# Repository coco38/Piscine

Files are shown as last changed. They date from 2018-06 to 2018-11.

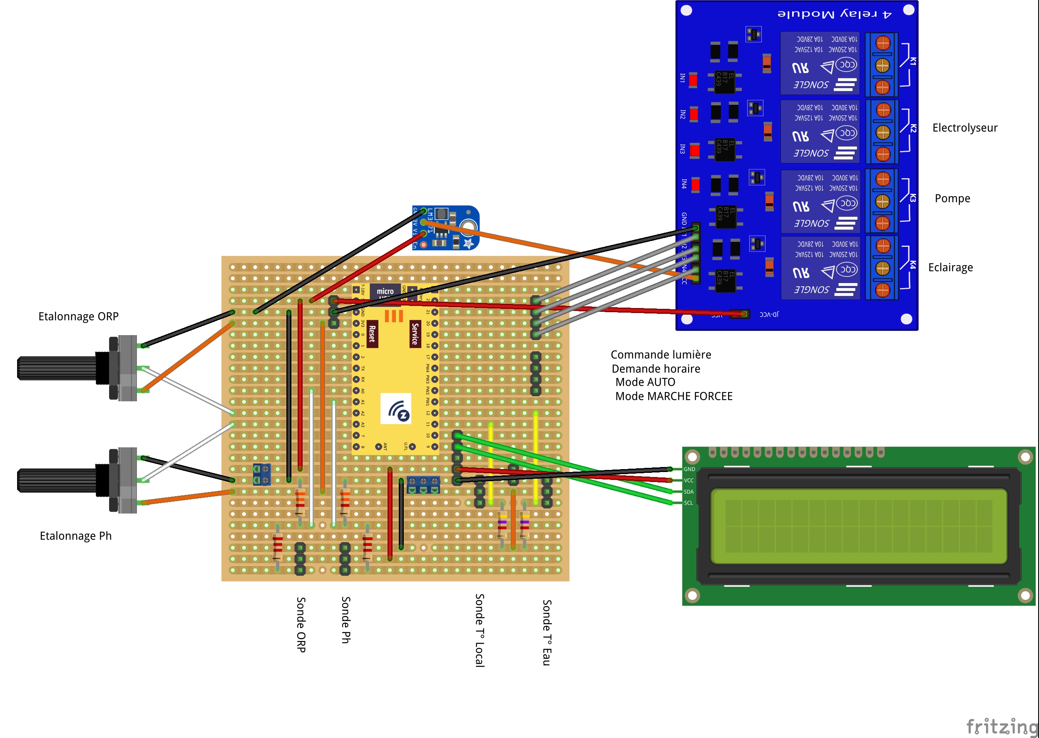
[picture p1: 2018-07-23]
Carte/Carte Design.jpg

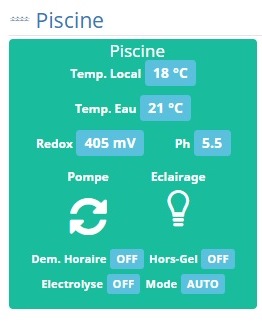
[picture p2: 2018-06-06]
Photos/Jeedom.jpg

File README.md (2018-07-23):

# Piscine

Pour ceux que ça intéresse, j'ai fait un automatisme largement inspiré du blog :
http://clement.storck.me/blog/2014/08/controle-et-supervision-de-la-piscine/

Pour les fonctions/informations, il intègre:
- remontée de la température du local
- remontée de la température de l'eau
- remontée du Ph
- remontée du Redox
- pilotage de l'éclairage à distance
- pilotage de la pompe à distance
- automatisme de la pompe
- régulation du chlore et mise en sécurité si la température de l'eau est inférieure à 15°C
- fonction Hors-Gel

Pour la gestion horaire, j'ai gardé la minuterie en façade de mon coffret d'origine.

Les 2 potentiomètres permettent de recaler les valeurs mesurées (ORP et Ph) pour corriger la dérive des sondes.

La principale différence par rapport au projet du blog citée précédemment, est le passage sur un Z-Uno. J'ai déjà un réseau Zwave et la gestion des commandes et des remontées d'informations à Jeedom est nettement plus facile.

Jérôme

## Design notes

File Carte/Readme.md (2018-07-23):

# Matériel:
- 1 carte Z-Uno
- 1 afficheur LCD 4x20 I2C
- 1 carte 4 relais 5V - 220V 10A
- 2 cartes Phidgets 1130
- 2 sondes de températures 1-Wire étanches (inox)
- 1 sonde ORP/Redox, plage du signal -2V/+2V
- 1 sonde de Ph, plage du signal 0V/1V
- 2 résistances 2,2kΩ
- 2 résistances 3.3kΩ
- 2 résistances 4.7kΩ
- 2 potentiomètres 10kΩ
- des fiches "Dupont" femelles, pas 1.54mm, à souder (pour enficher le Z-Uno)
- des fiches "Dupont" males, pas 1.54mm, à souder (pour brancher les sondes ORP, Ph et Températures)
- du fils et des connecteurs "Dupont" à sertir

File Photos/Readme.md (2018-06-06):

# Description des photos:
- Jeedom.jpg : vue du widget sous Jeedom
- Jeedom - Zuno commandes page 1.jpg : liste des commandes à créer (page 1)
- Jeedom - Zuno commandes page 2.jpg : liste des commandes à créer (page 2)
- Jeedom - Zuno valeurs.jpg : liste des valeurs remontées par le Zuno, suite à l'inclusion

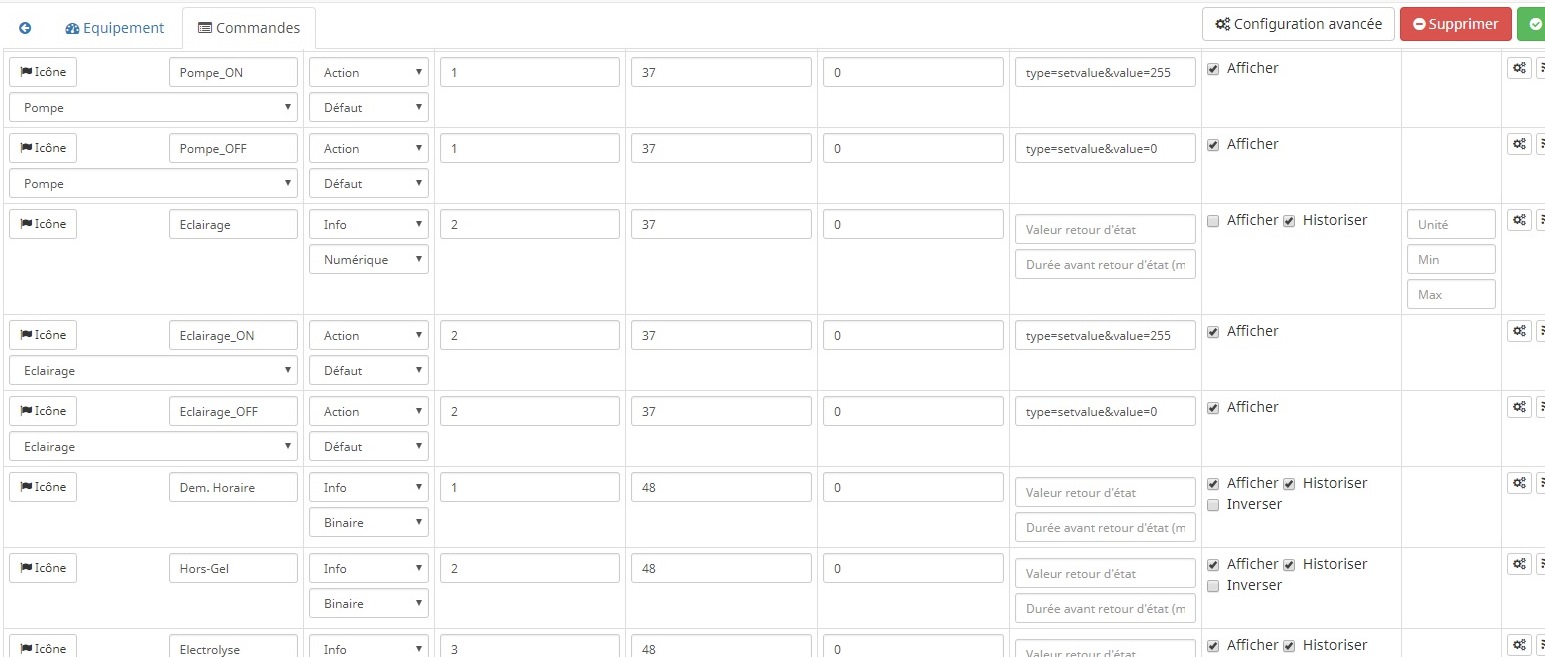
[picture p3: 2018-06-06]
Photos/Jeedom - Zuno commandes page 2.jpg

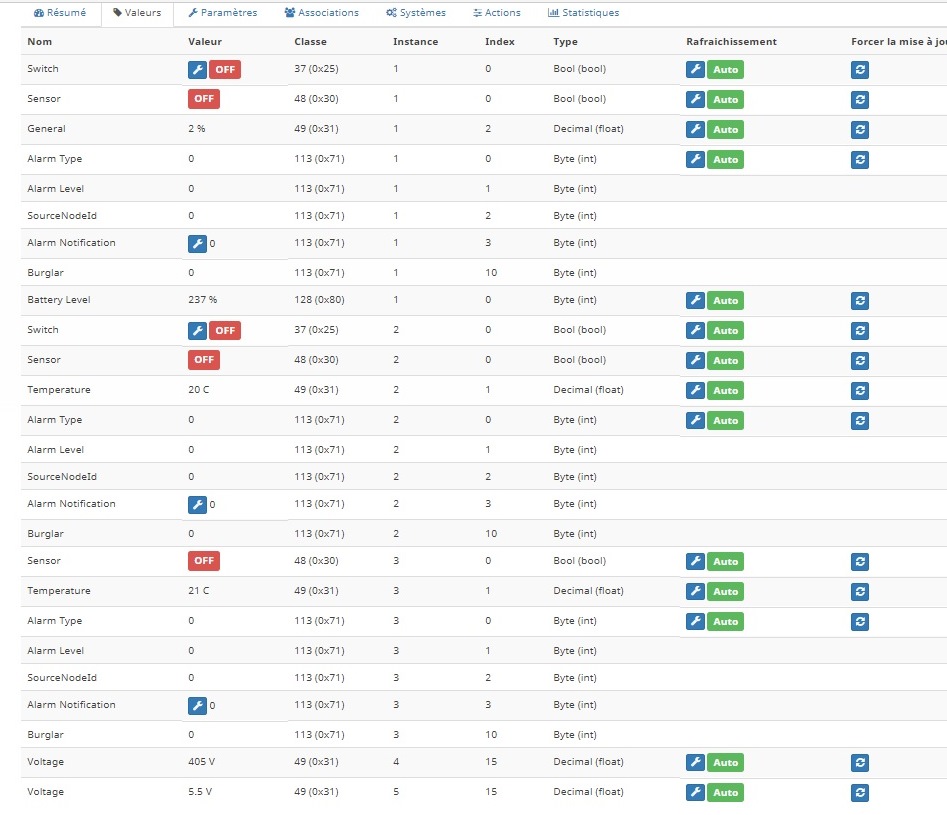
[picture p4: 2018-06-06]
Photos/Jeedom - Zuno valeurs.jpg

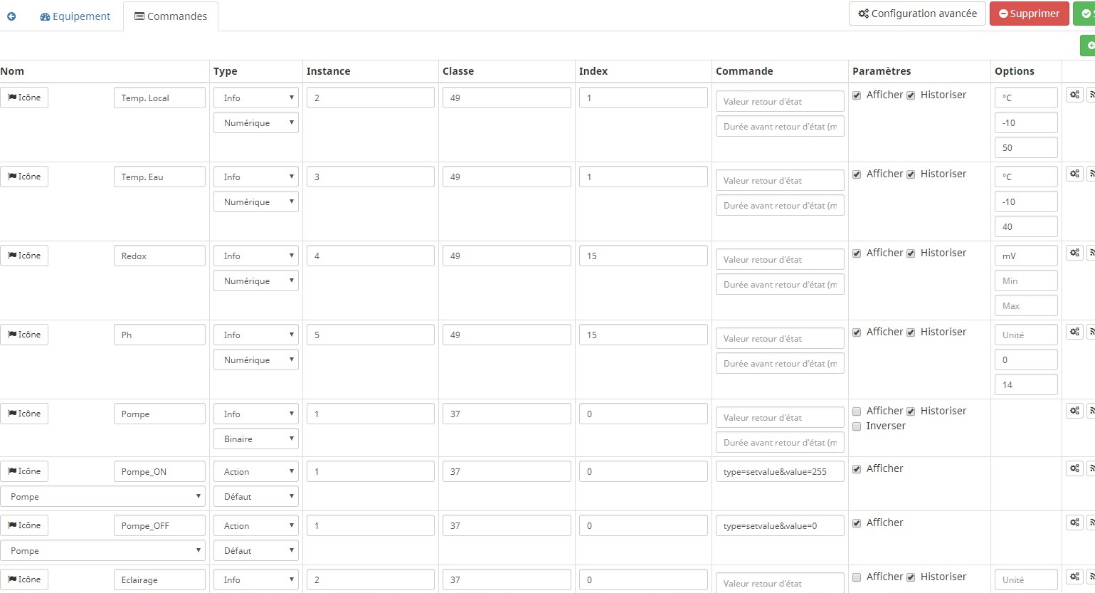
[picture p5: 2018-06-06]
Photos/Jeedom - Zuno commandes page 1.jpg

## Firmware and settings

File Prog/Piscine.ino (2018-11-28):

#include <ZUNO_OneWire.h>
#include <ZUNO_LCD_I2C.h>
#include <ZUNO_DS18B20.h>

/*******************************************
 * AFFECTATION DES PINS
 ******************************************/
//TEST
#define PIN_LED 13
#define PIN_BUTTON 18

//Entrée Ana
#define PIN_ORP         A0    // Pin de la sonde ORP
#define PIN_PH          A1    // Pin de la sonde PH
#define PIN_ORP_ETAL    A2    // Pin pour l'étalonnage de la sonde ORP
#define PIN_PH_ETAL     A3    // Pin pour l'étalonnage de la sonde PH

//Température
#define PIN_TEMP_LOCAL  11 // Pin du capteur DS18B20 : Température du local 
#define PIN_TEMP_EAU    12 // Pin du capteur DS18B20 : Température de l'eau

//Entrée TOR
#define PIN_MODE_MANU   14    // Pin du mode Manu
#define PIN_MODE_AUTO   15    // Pin du mode Auto
#define PIN_HORAIRE     16    // Pin du selecteur horaire
#define PIN_LUMIERE     17    // Pin du bouton lumiere

//Sortie relais
#define PIN_ECL_PISCINE   19  // Pin de l'éclairage de la piscine
#define PIN_POMP_PISCINE  20  // Pin de la pompe de la piscine
#define PIN_ELECTROLYSE   21  // Pin de l'electrolyseur

/*******************************************
 * CONSTANTES
 ******************************************/
//tension de reference (Vcc) du Zuno
#define VOLT_REFERENCE  3.05  // Tension de référence
 
//température
#define TEMP_GEL_MIN  -0.5  // Température de démarrage du mode antigel
#define TEMP_GEL_MAX   1.0  // Température d'arrêt du mode antigel
 
//ORP/Redox
#define ORP_MIN     660   // Tension (mV) de démarrage de la production de chlore
#define ORP_MAX     720   // Tension (mV) d'arrêt de la production de chlore

#define TempoMesure 300000  //attente entre chaque mesure
/******************************************
 * VARIABLES GLOBALES
 ******************************************/
//TEST
byte LedState;

//temporisation
unsigned long PrecMillis = 0;

//ecran lcd
LiquidCrystal_I2C lcd(0x3F, 20, 4);

//mode de fonctionnement
byte modePompe = 0; // 0:arret / 1:marche forcée / 2:auto
byte modePompePrec = 0;

//mesure de temperature
//Local
OneWire owTempLoc(PIN_TEMP_LOCAL);
DS18B20Sensor CapteurTempLoc(&owTempLoc);
int TemperatureLoc=0;
//Eau
OneWire owTempEau(PIN_TEMP_EAU);

DS18B20Sensor CapteurTempEau(&owTempEau);
int TemperatureEau=0;

//mesures
int valORP=0;
float valPH=0.0;

//sorties relais
//pompe
bool fctGel = false;
bool pinHoraire = false;
bool pinHorairePrec = false;
bool etatPompe = false;

//lumiere
bool pinLumiere = false;
bool pinLumierePrec = false;
bool etatLumiere = false;

//Chlore
bool etatChloreProd = false;

/******************************************
 * CANAUX ZWAVE
 * 1 : cmde de la pompe
 * 2 : cmde de la lumiere
 * 3 : mode AUTO (2) / MANU (1) / ARRET (0)
 * 4 : etat de la demande horaire
 * 5 : etat de la demande hors gel
 * 6 : température du local
 * 7 : température de l'eau
 * 8 : niveau ORP/Redox
 * 9 : niveau PH
 * 10 : etat production de Chlore
 ******************************************/

ZUNO_SETUP_CHANNELS(
  //Etat & commande de la pompe
  ZUNO_SWITCH_BINARY(getPompe, setPompe),
  //Etat & commande de la lumiere  
  ZUNO_SWITCH_BINARY(getLumiere, setLumiere),
  //Mode selectionne
  ZUNO_SENSOR_MULTILEVEL_GENERAL_PURPOSE(getMode),
  //Etat & commande de la pompe
  ZUNO_SENSOR_BINARY(ZUNO_SENSOR_BINARY_TYPE_GENERAL_PURPOSE, getHoraire),
  //Etat du mode hors-gel
  ZUNO_SENSOR_BINARY(ZUNO_SENSOR_BINARY_TYPE_GENERAL_PURPOSE, getGel),
  //Temperature du local
  ZUNO_SENSOR_MULTILEVEL(ZUNO_SENSOR_MULTILEVEL_TYPE_TEMPERATURE,SENSOR_MULTILEVEL_SCALE_CELSIUS, SENSOR_MULTILEVEL_SIZE_TWO_BYTES, SENSOR_MULTILEVEL_PRECISION_ONE_DECIMAL, getTempLocal),
  //Temperature de l'eau
  ZUNO_SENSOR_MULTILEVEL(ZUNO_SENSOR_MULTILEVEL_TYPE_TEMPERATURE,SENSOR_MULTILEVEL_SCALE_CELSIUS, SENSOR_MULTILEVEL_SIZE_TWO_BYTES, SENSOR_MULTILEVEL_PRECISION_ONE_DECIMAL, getTempEau),
  //ORP/Redox
  ZUNO_SENSOR_MULTILEVEL(ZUNO_SENSOR_MULTILEVEL_TYPE_VOLTAGE,SENSOR_MULTILEVEL_SCALE_VOLT, SENSOR_MULTILEVEL_SIZE_TWO_BYTES, SENSOR_MULTILEVEL_PRECISION_ZERO_DECIMALS, getORP),
  //Ph
  ZUNO_SENSOR_MULTILEVEL(ZUNO_SENSOR_MULTILEVEL_TYPE_VOLTAGE,SENSOR_MULTILEVEL_SCALE_VOLT, SENSOR_MULTILEVEL_SIZE_TWO_BYTES, SENSOR_MULTILEVEL_PRECISION_ONE_DECIMAL, getPH),
  //Etat de la production de chlore
  ZUNO_SENSOR_BINARY_GENERAL_PURPOSE(getChloreProd));

/******************************************
 * INITIALISATION
 ******************************************/
void setup() {
  //initialisation port serie
  Serial.begin(9600);
  Serial.println("Start...");

  Serial.println("Initialisation des sorties relais");
  pinMode(PIN_ECL_PISCINE, OUTPUT);
  pinMode(PIN_POMP_PISCINE, OUTPUT);
  pinMode(PIN_ELECTROLYSE, OUTPUT);

  Serial.println("Initialisation des entrees");
  pinMode(PIN_MODE_MANU, INPUT_PULLUP);
  pinMode(PIN_MODE_AUTO, INPUT_PULLUP);
  pinMode(PIN_HORAIRE, INPUT_PULLUP);
  pinMode(PIN_LUMIERE, INPUT_PULLUP);
        
  //initialisation écran lcd
  Serial.println("Initialisation de l'ecran LCD");
  delay(300);
  lcd.begin();
  lcd.backlight();
  lcd.setCursor(0,0);
  lcd.print("T");lcd.print((char)223);lcd.print(" Local:");
  lcd.setCursor(13,0);
  lcd.print("Eau:");
  lcd.setCursor(0,1);
  lcd.print("Redox:       ");
  lcd.setCursor(13,1);
  lcd.print("Ph:    ");
  lcd.setCursor(0,2);
  lcd.print("Mode:ARRET");
  lcd.setCursor(13,2);
  lcd.print("Lum:OFF");
  lcd.setCursor(0,3);
  lcd.print("Pompe:OFF Chlore:OFF"); 
  delay(100);
  
  pinMode(PIN_LED, OUTPUT);
  pinMode(PIN_BUTTON, INPUT_PULLUP);

  digitalWrite(PIN_LED, LOW);
  LedState=0;

  //initialisation des relais
  Serial.println("Initialisation des sorties relais");
  digitalWrite(PIN_ECL_PISCINE, HIGH);
  digitalWrite(PIN_POMP_PISCINE, HIGH);
  digitalWrite(PIN_ELECTROLYSE, HIGH);  

  PrecMillis = millis();
}

void loop() {

  lectureEntrees();
  
  if ((digitalRead(PIN_BUTTON)==0) || ((millis() - PrecMillis) >= TempoMesure)) {

    PrecMillis = millis();
    
    Serial.println("Button pressed");
    if(LedState==0){
      digitalWrite(PIN_LED, HIGH);
      LedState = 1;
      Serial.println("Led On");
    }
    else{
      digitalWrite(PIN_LED, LOW);
      LedState = 0;
      Serial.println("Led Off");    
    }

    //mesure de la température du local
    lectureTempLocal();    

    //si la pompe fonctionne, on fait les mesures de l'eau (ORP, PH, Temperature)
    if(etatPompe){

      lectureTempEau();
      lectureORP();
      lecturePH();
    }

    zunoSendReport(1);
    zunoSendReport(2);
    zunoSendReport(3);
    zunoSendReport(4);
    zunoSendReport(5);
    zunoSendReport(10);
  }

  //Mise à jour du fonctionnement de la pompe
  FctPompe();
  
  //pilotage du relais de la pompe et mise à jour de l'affichage LCD
  //Edit 29-Sep-2018
  if(etatPompe){
    digitalWrite(PIN_POMP_PISCINE,LOW);
    lcd.setCursor (6, 3);
    lcd.print("ON ");    
  }
  else{
    digitalWrite(PIN_POMP_PISCINE,HIGH);
    lcd.setCursor (6, 3);
    lcd.print("OFF");  
  }

  FctLumiere();
  
  //pilotage du relais de la lumiere et mise à jour de l'affichage LCD
  //Edit 29-Sep-2018 
  if(etatLumiere){
    digitalWrite(PIN_ECL_PISCINE, LOW);
    lcd.setCursor(17,2);
    lcd.print("ON ");
  }
  else {
    digitalWrite(PIN_ECL_PISCINE, HIGH);
    lcd.setCursor(17,2);
    lcd.print("OFF");    
  }

  FctProdChlore();
  
  //pilotage du relais de la production de chlore et mise à jour de l'affichage LCD
  //Edit 29-Sep-2018
  if(etatChloreProd){
    digitalWrite(PIN_ELECTROLYSE, LOW);
    lcd.setCursor (17, 3);
    lcd.print("ON ");
  }
  else {
    digitalWrite(PIN_ELECTROLYSE, HIGH);
    lcd.setCursor (17, 3);
    lcd.print("OFF");  
  }
  delay(120);
}

/****************************************************************************
 * FONCTION : récupère la température de l'eau du capteur DS18B20
 *  sans objet
 ****************************************************************************/
void lectureTempEau(){
  byte adresse[8];
  float temperature;
      
  //si le capteur est trouvé
  if(CapteurTempEau.scanAloneSensor(adresse)) {
      
      Serial.print("Adresse du capteur de temperature de l'eau ");
      for(int j = 0; j < 8; j++) {
        Serial.print(adresse[j], HEX);
        Serial.print(" ");
      }  
      Serial.println();  

      lcd.setCursor (17, 0);
      lcd.print("   "); // Clean lcd old digits
        
      //si la lecture est correcte
      temperature = CapteurTempEau.getTemperature(adresse);

      if((int)CapteurTempEau.getTemperature(adresse) != BAD_TEMP) {
        Serial.print("Temperature: ");
        Serial.println(temperature); 

        TemperatureEau = temperature;
        zunoSendReport(7);

        lcd.setCursor (17, 0);
        lcd.print((int)temperature);
        lcd.print((char)223); 
      }
      else {
        Serial.println("Temperature de l'eau erronee");
        
        lcd.setCursor (17, 0);
        lcd.print("TMP");
      }
    }
    else {
      Serial.println("Capteur de temperature de l'eau non trouve!");
      
      lcd.setCursor (17, 0);
      lcd.print("CAP");
    }

}

/****************************************************************************
 * FONCTION : récupère la température du local du capteur DS18B20
 *  sans objet
 ****************************************************************************/
void lectureTempLocal(){
  byte adresse[8];
  float temperature;
      
  //si le capteur est trouvé
  if(CapteurTempLoc.scanAloneSensor(adresse)) {
      
      Serial.print("Adresse du capteur de temperature du local ");
      for(int j = 0; j < 8; j++) {
        Serial.print(adresse[j], HEX);
        Serial.print(" ");
      }  
      Serial.println();  

      lcd.setCursor (9, 0);
      lcd.print("    "); // Clean lcd old digits
        
      //si la lecture est correcte
      temperature = CapteurTempLoc.getTemperature(adresse);

      if((int)CapteurTempLoc.getTemperature(adresse) != BAD_TEMP) {
        Serial.print("Temperature: ");
        Serial.println(temperature); 

        TemperatureLoc = temperature;
        zunoSendReport(6);
    
        lcd.setCursor (9, 0);
        lcd.print((int)temperature);
        lcd.print((char)223); 
      }
      else {
        Serial.println("Temperature du local erronee");
  
        lcd.setCursor (9, 0);
        lcd.print("TMP");
      }
    }
    else {
      Serial.println("Capteur de temperature du local non trouve!");

      lcd.setCursor (9, 0);
      lcd.print("CAP");
    }

}

/****************************************************************************
 * FONCTION : active la pompe de la piscine en cas de gel
 *  sans objet
 ****************************************************************************/
void FctPompe(){
  bool etatPompePrec = etatPompe;
  bool fctGelPrec = fctGel;
  
  //si la température du local < TEMP MIN => Gel
  if(TemperatureLoc < TEMP_GEL_MIN){
    fctGel = true;
  }
  if(TemperatureLoc > TEMP_GEL_MAX){
    fctGel = false;
  }

  //selon le MODE selectionné
  switch(modePompe){
    //ARRET
    case 0:
      etatPompe = false;
      break;
    //MARCHE FORCEE
    case 1:
      etatPompe = true;
      break;
    //AUTO
    case 2:
      //si le mode Auto vient d'être activé => on prend l'état de la demande horaire
      if(modePompe && !modePompePrec){
        etatPompe = pinHoraire;
      }

      //si le mode hors gel est activé => marche de la pompe en priorité
      if(fctGel){
        etatPompe = true;
      }
      else{
        //demande d'arrêt de la pompe SI
        //Arret_Horaire OU (Fin du mode Hors Gel ET pas de Demande_Horaire
        if((!pinHoraire && pinHorairePrec) || (!fctGel && fctGelPrec && !pinHoraire)){
          etatPompe = false;          
        }
        //demande de démarrage de la pompe SI
        //Arret_Horaire OU (Fin du mode Hors Gel ET pas de Demande_Horaire        
        if(pinHoraire && !pinHorairePrec) {
          etatPompe = true;
        }
      }
      break;
    default:
      etatPompe = false;
  }

  //si l'état de la pompe à changer, on signale au controleur zwave
  if(etatPompe != etatPompePrec){
    zunoSendReport(1);
    //Edit 29-Sep-2018
    //Serial.print("Passage de la pompe : "); Serial.println(etatPompe);
    //lcd.setCursor (6, 3);
    //if(etatPompe ==  false){
    //  lcd.print("OFF");
    //}
    //else {
    //  lcd.print("ON ");      
    //}
  }

  //si le mode à changer, on signale au controleur zwave et on met à jour l'affichage LCD
  if(modePompe != modePompePrec){
    zunoSendReport(3);
    Serial.print("Passage en mode : "); Serial.println(modePompe);

    lcd.setCursor (5, 2);
    switch(modePompe){
      case 0:
        lcd.print("ARRET ");
        break;
      case 1:
        lcd.print("MARCHE");
        break;
      case 2:
        lcd.print("AUTO  ");
        break;
    }
  }  

  //si le mode hors gel à changer, on signale au controleur zwave
  if(fctGel != fctGelPrec){
    zunoSendReport(5);
    Serial.print("hors gel : "); Serial.println(fctGel);    
  }
  
  //Memorise l'état des entrées
  pinHorairePrec = pinHoraire;
  modePompePrec = modePompe;
}

/****************************************************************************
 * FONCTION : change l'état de la lumiere à chaque appui sur le bouton
 *  sans objet
 ****************************************************************************/
void FctLumiere(){
  if(pinLumiere && !pinLumierePrec){
    etatLumiere = !etatLumiere;
    Serial.print("Appui sur le bouton lumiere: ");Serial.println(etatLumiere);
    zunoSendReport(1);
  }

  pinLumierePrec = pinLumiere;
}

/****************************************************************************
 * FONCTION : regule le chlore de la piscine
 *  sans objet
 ****************************************************************************/
void FctProdChlore(){
    bool etatChloreProdPrec;

    etatChloreProdPrec = etatChloreProd;
    // si le niveau de chlore est trop bas, 
    // ET la pompe fonctionne 
    // ET la température de l'eau est supérieur à 15°C
    // => on demarre la production de chlore
    if((valORP < ORP_MIN) && (etatPompe) && (TemperatureEau > 15.0)){
      etatChloreProd = true;
    }
    // si le niveau de chlore est trop haut
    // OU la pompe ne fonctionne pas 
    // OU la température de l'eau est inférieur à 15°C
    // => on arrete la production de chlore
    if((valORP > ORP_MAX)||(!etatPompe) || ((TemperatureEau < 15.0))){
      etatChloreProd = false;      
    }

    //si le etat de la production de chlore a changé, on signale au controleur zwave et on met à jour l'affichage LCD
    if(etatChloreProd != etatChloreProdPrec){
      zunoSendReport(10);
      //Edit 29-Sep-2018
      //Serial.print("Electrolyseur: "); Serial.println(etatChloreProd);    
      //lcd.setCursor (17, 3);
      //if(etatChloreProd ==  false){
      //  lcd.print("OFF");
      //}
      //else {
      //  lcd.print("ON ");      
      //}
    }
  
}

/****************************************************************************
 * FONCTION : lit les entrées et les stock dans des variables
 *  sans objet
 ****************************************************************************/
void lectureEntrees(){
  bool modeAuto;
  bool modeManu;
  
  pinHoraire = !digitalRead(PIN_HORAIRE);
  modeManu = !digitalRead(PIN_MODE_MANU);
  modeAuto = !digitalRead(PIN_MODE_AUTO);
  modePompe = (byte)((modeAuto <<1)|(modeManu));
  pinLumiere = !digitalRead(PIN_LUMIERE);

  //si la demande horaire a changé
  if(pinHoraire != pinHorairePrec){
      zunoSendReport(4); 
  }

  //si l'état de la lumiere a changé
  if(pinLumiere != pinLumierePrec){
      zunoSendReport(2);
  }

}

/****************************************************************************
 * FONCTION : lit la sonde ORP/Redox
 *  sans objet
 ****************************************************************************/
void lectureORP(){
    int valueADC;
    float value,ValueEtalon;
        
    valueADC = analogRead(PIN_ORP);
    value = (float)(valueADC) * 1.55 * 1000 * VOLT_REFERENCE / 1024; //1,55: rapport du pont diviseur
    value = (2080-value)/0.875;
    valueADC = analogRead(PIN_ORP_ETAL);
    ValueEtalon = ((float)(valueADC) * 600 / 1024) - 400;
    valORP = value + ValueEtalon;

    Serial.print("ORP: ");Serial.println(valORP);

    //Edit 29-Sep-2018
    lcd.setCursor(0,1);
    lcd.print("Redox:       ");
    lcd.setCursor (6, 1);
    lcd.print(valORP);
    lcd.print("mV");
    zunoSendReport(8);

}

/****************************************************************************
 * FONCTION : lit lit la sonde PH
 *  sans objet
 ****************************************************************************/
void lecturePH(){
    int valueADC;
    float value,ValueEtalon;
    
    valueADC = analogRead(PIN_PH)*VOLT_REFERENCE;
    value = (float)(valueADC) / 1024 * 1.55; //1,55: rapport du pont diviseur
    valueADC = analogRead(PIN_PH_ETAL);
    ValueEtalon = ((float)(valueADC) / 1024 * 4)-1;
    valPH = 7-((2.5-value)/(0.257179+0.000941468*TemperatureEau))+ValueEtalon;

    Serial.print("PH: ");Serial.println(valPH);

    //Edit 29-Sep-2018
    lcd.setCursor (13,1);
    lcd.print("Ph:    ");
    lcd.setCursor (16,1);
    lcd.print(valPH,1);
    zunoSendReport(9);
}

/******************************************
 * FONCTIONS CANAUX ZWAVE : POMPE
 ******************************************/
void setPompe(byte value) {
  if((modePompe == 2) && (!fctGel)){
    
    if (value > 0) {               // if greater then zero
      etatPompe = true;
    } 
    else {                         // if equals zero
      etatPompe = false;
    }
  }
}

byte getPompe() {
  return (byte)etatPompe;
}

/******************************************
 * FONCTIONS CANAUX ZWAVE : LUMIERE
 ******************************************/
void setLumiere(byte value) {
  if (value > 0) {               // if greater then zero
    etatLumiere = true;
  } 
  else {                         // if equals zero
    etatLumiere = false;
  }
}

byte getLumiere() {
  return (byte)etatLumiere;
}

/******************************************
 * FONCTIONS CANAUX ZWAVE : MODE
 ******************************************/
byte getMode() {
  return (modePompe);
}

/******************************************
 * FONCTIONS CANAUX ZWAVE : DEMANDE HORAIRE
 ******************************************/
byte getHoraire() {
  return (byte)pinHoraire;
}

/******************************************
 * FONCTIONS CANAUX ZWAVE : MODE ANTIGEL
 ******************************************/
byte getGel() {
  return (byte)fctGel;
}

/******************************************
 * FONCTIONS CANAUX ZWAVE : TEMPERATURE LOCAL
 ******************************************/
int getTempLocal(){
  return (TemperatureLoc*10);
}

/******************************************
 * FONCTIONS CANAUX ZWAVE : TEMPERATURE EAU
 ******************************************/
int getTempEau(){
  return (TemperatureEau*10);
}

/******************************************
 * FONCTIONS CANAUX ZWAVE : ORP/REDOX
 ******************************************/
int getORP(){
  return (valORP);
}

/******************************************
 * FONCTIONS CANAUX ZWAVE : PH
 ******************************************/
int getPH(){
  return (int)(valPH*10);
}

/******************************************
 * FONCTIONS CANAUX ZWAVE : CHLORE PRODUCTION
 ******************************************/
byte getChloreProd(){
  return (byte)(etatChloreProd);
}

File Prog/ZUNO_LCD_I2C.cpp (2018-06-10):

#include "ZUNO_LCD_I2C.h"
#include <Arduino.h>
#include <Wire.h>

// When the display powers up, it is configured as follows:
//
// 1. Display clear
// 2. Function set:
//    DL = 1; 8-bit interface data
//    N = 0; 1-line display
//    F = 0; 5x8 dot character font
// 3. Display on/off control:
//    D = 0; Display off
//    C = 0; Cursor off
//    B = 0; Blinking off
// 4. Entry mode set:
//    I/D = 1; Increment by 1
//    S = 0; No shift
//
// Note, however, that resetting the Arduino doesn't reset the LCD, so we
// can't assume that its in that state when a sketch starts (and the
// LiquidCrystal constructor is called).

LiquidCrystal_I2C::LiquidCrystal_I2C(uint8_t lcd_addr, uint8_t lcd_cols, uint8_t lcd_rows, uint8_t charsize)
{
	_addr = lcd_addr;
	_cols = lcd_cols;
	_rows = lcd_rows;
	_charsize = charsize;
	_backlightval = LCD_BACKLIGHT;
}

void LiquidCrystal_I2C::begin() {
	Wire.begin();
	_displayfunction = LCD_4BITMODE | LCD_1LINE | LCD_5x8DOTS;

	if (_rows > 1) {
		_displayfunction |= LCD_2LINE;
	}

	// for some 1 line displays you can select a 10 pixel high font
	if ((_charsize != 0) && (_rows == 1)) {
		_displayfunction |= LCD_5x10DOTS;
	}

	// SEE PAGE 45/46 FOR INITIALIZATION SPECIFICATION!
	// according to datasheet, we need at least 40ms after power rises above 2.7V
	// before sending commands. Arduino can turn on way befer 4.5V so we'll wait 50
	delay(50);

	// Now we pull both RS and R/W low to begin commands
	expanderWrite(_backlightval);	// reset expanderand turn backlight off (Bit 8 =1)
	delay(1000);

	//put the LCD into 4 bit mode
	// this is according to the hitachi HD44780 datasheet
	// figure 24, pg 46

	// we start in 8bit mode, try to set 4 bit mode
	write4bits(0x03 << 4);
	delayMicroseconds(4500); // wait min 4.1ms

	// second try
	write4bits(0x03 << 4);
	delayMicroseconds(4500); // wait min 4.1ms

	// third go!
	write4bits(0x03 << 4);
	delayMicroseconds(150);

	// finally, set to 4-bit interface
	write4bits(0x02 << 4);

	// set # lines, font size, etc.
	command(LCD_FUNCTIONSET | _displayfunction);

	// turn the display on with no cursor or blinking default
	_displaycontrol = LCD_DISPLAYON | LCD_CURSOROFF | LCD_BLINKOFF;
	display();

	// clear it off
	clear();

	// Initialize to default text direction (for roman languages)
	_displaymode = LCD_ENTRYLEFT | LCD_ENTRYSHIFTDECREMENT;

	// set the entry mode
	command(LCD_ENTRYMODESET | _displaymode);

	home();
}

/********** high level commands, for the user! */
void LiquidCrystal_I2C::clear(){
	command(LCD_CLEARDISPLAY);// clear display, set cursor position to zero
	delayMicroseconds(2000);  // this command takes a long time!
}

void LiquidCrystal_I2C::home(){
	command(LCD_RETURNHOME);  // set cursor position to zero
	delayMicroseconds(2000);  // this command takes a long time!
}

void LiquidCrystal_I2C::setCursor(uint8_t col, uint8_t row){
	uint8_t row_offsets[4];
	row_offsets[0] = 0x00;
	row_offsets[1] = 0x40;
	row_offsets[2] = 0x14;
	row_offsets[3] = 0x54;

	if (row > _rows) {
		row = _rows-1;    // we count rows starting w/0
	}

	command(LCD_SETDDRAMADDR | (col + row_offsets[row]));
}

// Turn the display on/off (quickly)
void LiquidCrystal_I2C::noDisplay() {
	_displaycontrol &= ~LCD_DISPLAYON;
	command(LCD_DISPLAYCONTROL | _displaycontrol);
}
void LiquidCrystal_I2C::display() {
	_displaycontrol |= LCD_DISPLAYON;
	command(LCD_DISPLAYCONTROL | _displaycontrol);
}

// Turns the underline cursor on/off
void LiquidCrystal_I2C::noCursor() {
	_displaycontrol &= ~LCD_CURSORON;
	command(LCD_DISPLAYCONTROL | _displaycontrol);
}
void LiquidCrystal_I2C::cursor() {
	_displaycontrol |= LCD_CURSORON;
	command(LCD_DISPLAYCONTROL | _displaycontrol);
}

// Turn on and off the blinking cursor
void LiquidCrystal_I2C::noBlink() {
	_displaycontrol &= ~LCD_BLINKON;
	command(LCD_DISPLAYCONTROL | _displaycontrol);
}
void LiquidCrystal_I2C::blink() {
	_displaycontrol |= LCD_BLINKON;
	command(LCD_DISPLAYCONTROL | _displaycontrol);
}

// These commands scroll the display without changing the RAM
void LiquidCrystal_I2C::scrollDisplayLeft(void) {
	command(LCD_CURSORSHIFT | LCD_DISPLAYMOVE | LCD_MOVELEFT);
}
void LiquidCrystal_I2C::scrollDisplayRight(void) {
	command(LCD_CURSORSHIFT | LCD_DISPLAYMOVE | LCD_MOVERIGHT);
}

// This is for text that flows Left to Right
void LiquidCrystal_I2C::leftToRight(void) {
	_displaymode |= LCD_ENTRYLEFT;
	command(LCD_ENTRYMODESET | _displaymode);
}

// This is for text that flows Right to Left
void LiquidCrystal_I2C::rightToLeft(void) {
	_displaymode &= ~LCD_ENTRYLEFT;
	command(LCD_ENTRYMODESET | _displaymode);
}

// This will 'right justify' text from the cursor
void LiquidCrystal_I2C::autoscroll(void) {
	_displaymode |= LCD_ENTRYSHIFTINCREMENT;
	command(LCD_ENTRYMODESET | _displaymode);
}

// This will 'left justify' text from the cursor
void LiquidCrystal_I2C::noAutoscroll(void) {
	_displaymode &= ~LCD_ENTRYSHIFTINCREMENT;
	command(LCD_ENTRYMODESET | _displaymode);
}

// Allows us to fill the first 8 CGRAM locations
// with custom characters
void LiquidCrystal_I2C::createChar(uint8_t location, uint8_t charmap[]) {
	location &= 0x7; // we only have 8 locations 0-7
	command(LCD_SETCGRAMADDR | (location << 3));
	for (int i=0; i<8; i++) {
		write(charmap[i]);
	}
}

// Turn the (optional) backlight off/on
void LiquidCrystal_I2C::noBacklight(void) {
	_backlightval=LCD_NOBACKLIGHT;
	expanderWrite(0);
}

void LiquidCrystal_I2C::backlight(void) {
	_backlightval=LCD_BACKLIGHT;
	expanderWrite(0);
}
bool LiquidCrystal_I2C::getBacklight() {
  return _backlightval == LCD_BACKLIGHT;
}


/*********** mid level commands, for sending data/cmds */

inline void LiquidCrystal_I2C::command(uint8_t value) {
	send(value, 0);
}

inline void LiquidCrystal_I2C::write(uint8_t value) {
	send(value, Rs);
}


/************ low level data pushing commands **********/

// write either command or data
void LiquidCrystal_I2C::send(uint8_t value, uint8_t mode) {
	uint8_t highnib=value&0xf0;
	uint8_t lownib=(value<<4)&0xf0;
	write4bits((highnib)|mode);
	write4bits((lownib)|mode);
}

void LiquidCrystal_I2C::write4bits(uint8_t value) {
	expanderWrite(value);
	pulseEnable(value);
}

void LiquidCrystal_I2C::expanderWrite(uint8_t _data){
	Wire.beginTransmission(_addr);
	Wire.write((int)(_data) | _backlightval);
	Wire.endTransmission();
}

void LiquidCrystal_I2C::pulseEnable(uint8_t _data){
	expanderWrite(_data | En);	// En high
	delayMicroseconds(1);		// enable pulse must be >450ns

	expanderWrite(_data & ~En);	// En low
	delayMicroseconds(50);		// commands need > 37us to settle
}
